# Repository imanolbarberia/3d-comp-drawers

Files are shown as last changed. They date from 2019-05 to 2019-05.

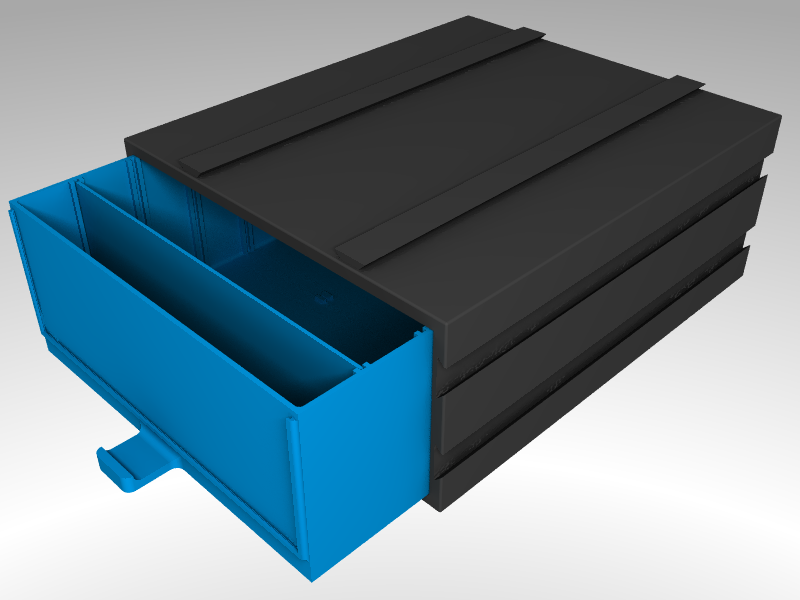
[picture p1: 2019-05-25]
renderer/1story_big.png

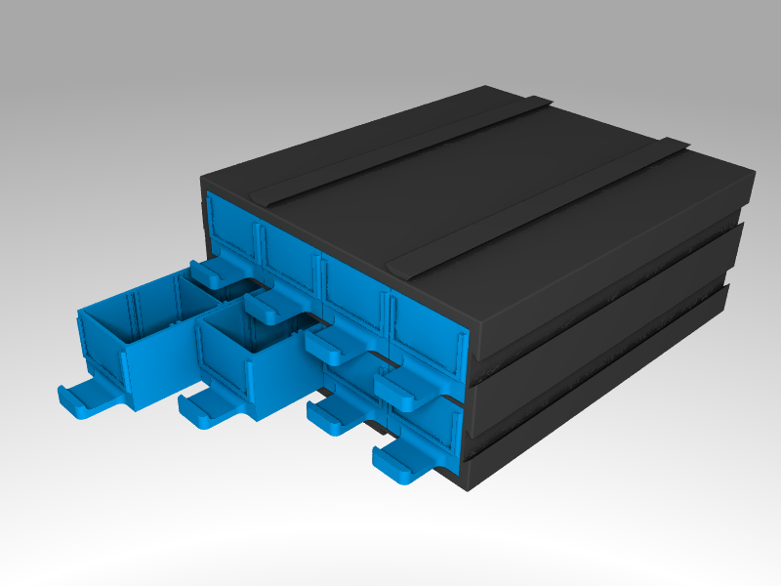
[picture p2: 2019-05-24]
renderer/2story_small.png

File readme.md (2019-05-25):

# Electronic Components Drawers and Cabinet

This project is for creating a cabinet and drawers for storing electronic components and small parts. Preferably only free and open source tools will be used, but in some cases it may not be feasible.

---
### Status
* Version: v2.0
* Released 
  * 1 story version: https://www.thingiverse.com/thing:3651857
  * 2 story version: https://www.thingiverse.com/thing:2868765
---
### Tools used
##### Software:
* [FreeCAD](https://www.freecadweb.org/): 3D CAD software
* [Ultimaker Cura](https://ultimaker.com/en/products/ultimaker-cura-software): Slicing software for converting 3D models into printable objects
##### Hardware:
* [Anycubic I3 Mega](https://www.amazon.com/Anycubic-3D-171-Upgraded-PRINTER-Heated/dp/B074NZPHJ5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): 3D printer

---
### Authors:
* Imanol Barberia (imanol.barberia@gmail.com)

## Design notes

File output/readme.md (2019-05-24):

### /output/
This is the output folder, where all the printable files will be stored

### STL Files
* **cabinet.stl**: Mesh for the cabinet object
* **drawer_tiny.stl**: Mesh for the Tiny drawer object
* **drawer_small.stl**: Mesh for the Small drawer object
* **drawer_standard.stl**: Mesh for the Standard drawer object
* **drawer_big.stl**: Mesh for the Big drawer object

### GCode
3D printing parameters used for the models:
* **Layer height**: 0.2 mm
* **Printing temperature**: 210 ºC
* **Build plate temperature**: 50 ºC
* **Enable retraction**: Yes
* **Print speed**: 60 mm/s
* **Travel speed**: 120 mm/s
* **Generate support**: No

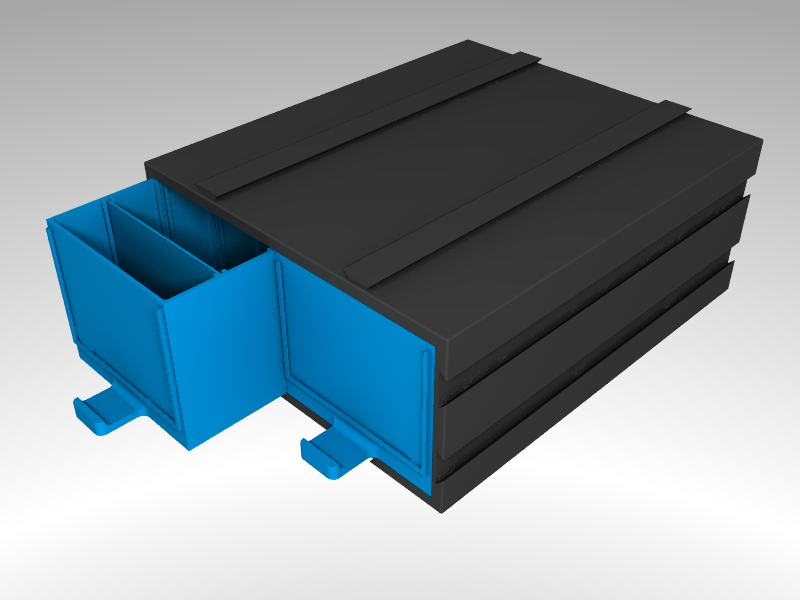
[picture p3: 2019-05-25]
renderer/1story_standard.png

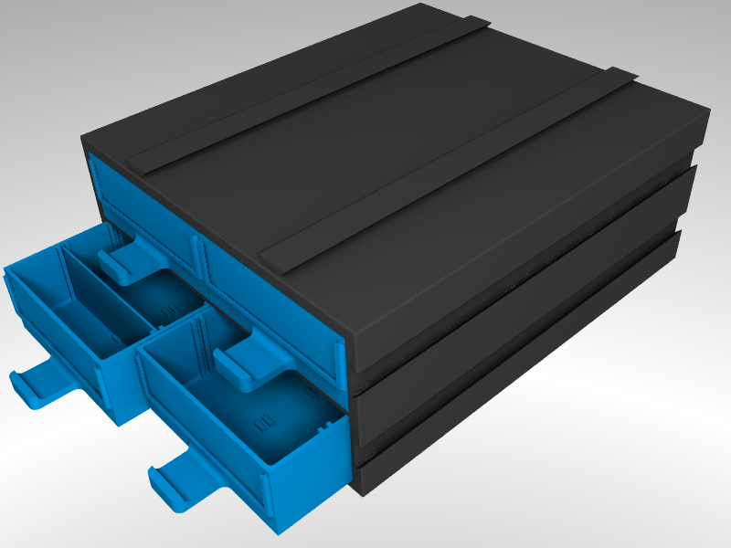
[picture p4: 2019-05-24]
renderer/2story_standard.png

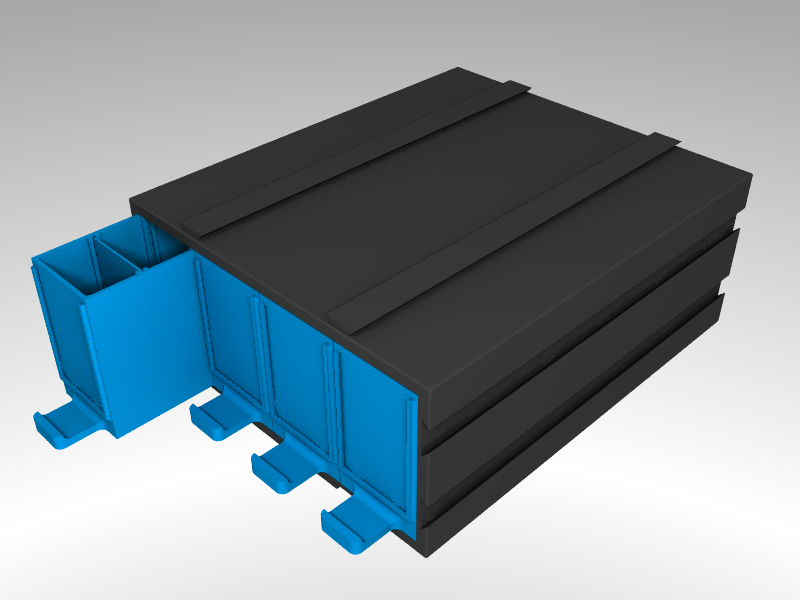
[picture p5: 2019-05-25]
renderer/1story_small.png

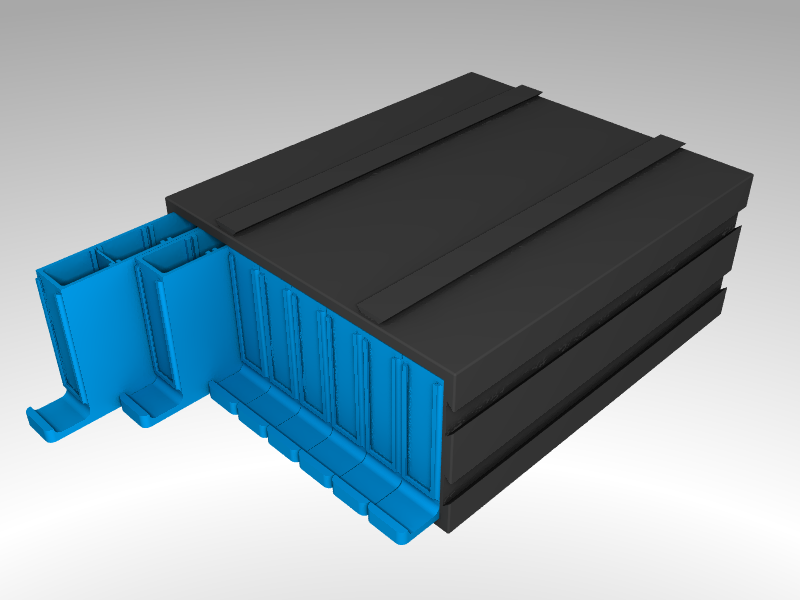
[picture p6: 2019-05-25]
renderer/1story_tiny.png

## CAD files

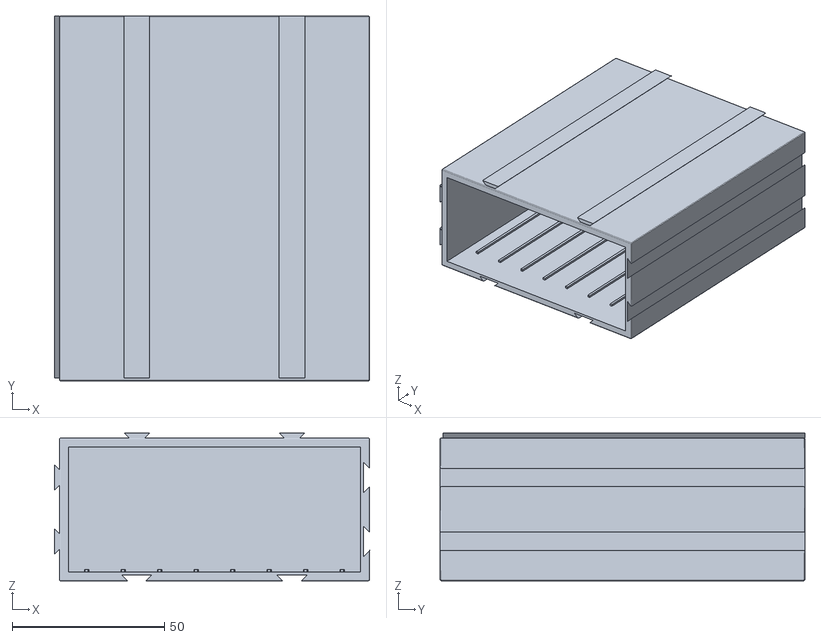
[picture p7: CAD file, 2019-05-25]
output/1story_cabinet.stl
103.6 x 120.0 x 48.6

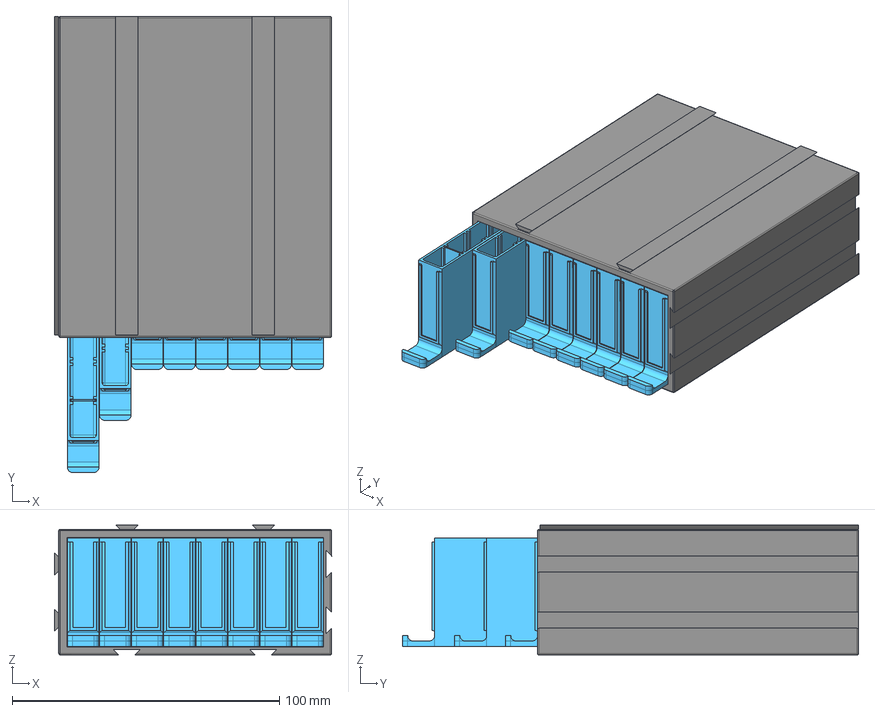
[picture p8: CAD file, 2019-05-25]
renderer/1story_renderer.fcstd
103.6 x 170.5 x 48.6 mm
tiny_separator_000
tiny_drawer_000
tiny_drawer_001
tiny_drawer_002
tiny_drawer_003
tiny_drawer_004
tiny_drawer_005
tiny_drawer_006
tiny_drawer_007
FinalCabinet

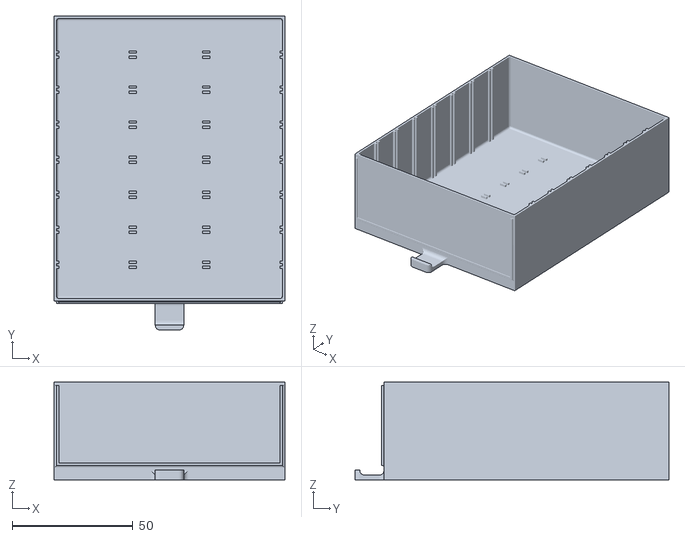
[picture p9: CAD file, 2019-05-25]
output/1story_drawer_big.stl
95.5 x 130.0 x 40.5

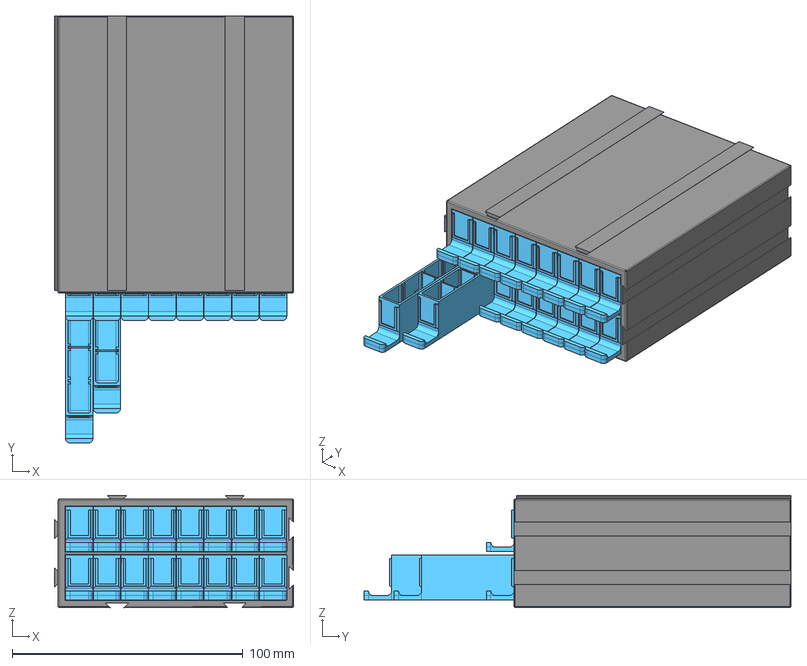
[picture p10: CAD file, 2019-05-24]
renderer/2story_renderer.fcstd
103.6 x 185.0 x 48.6 mm
tiny_separator_000
tiny_separator_001
tiny_separator_002
tiny_separator_003
tiny_drawer_000
tiny_drawer_001
tiny_drawer_002
tiny_drawer_003
tiny_drawer_004
tiny_drawer_005
tiny_drawer_006
tiny_drawer_007
tiny_drawer_014
tiny_drawer_008
tiny_drawer_011
tiny_drawer_013
tiny_drawer_010
tiny_drawer_015
tiny_drawer_009
tiny_drawer_012
Final Cabinet

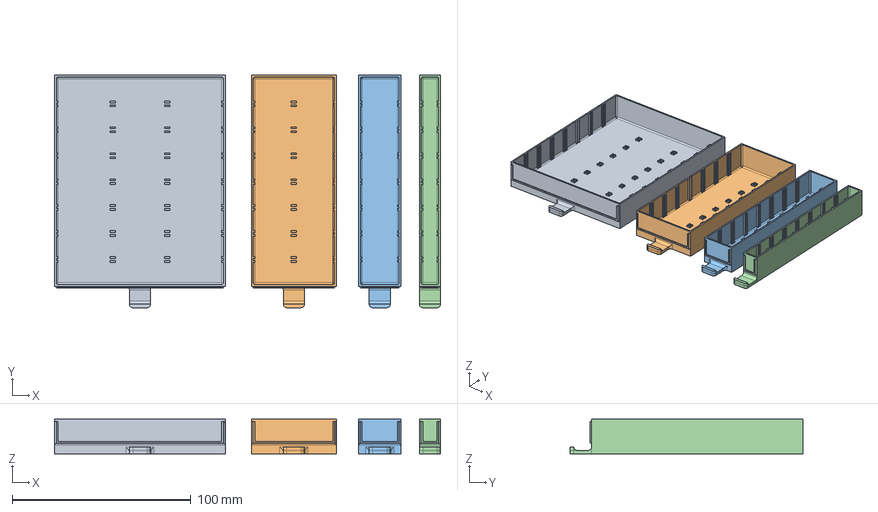
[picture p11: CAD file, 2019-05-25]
src/2story_drawers.fcstd
215.8 x 130.0 x 19.5 mm
BigDrawer
StandardDrawer
SmallDrawer
TinyDrawer

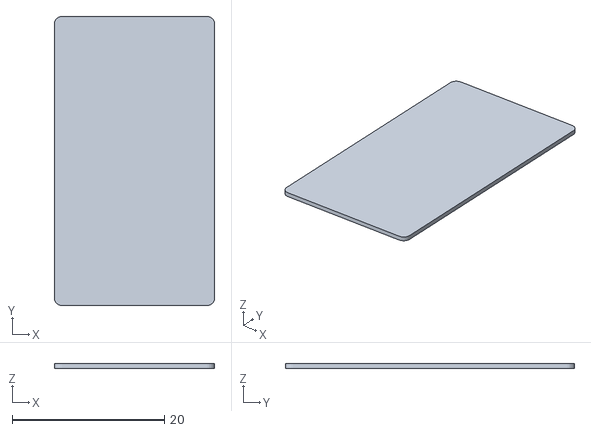
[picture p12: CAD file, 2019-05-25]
output/1story_separator_small.stl
21.1 x 38.0 x 0.6

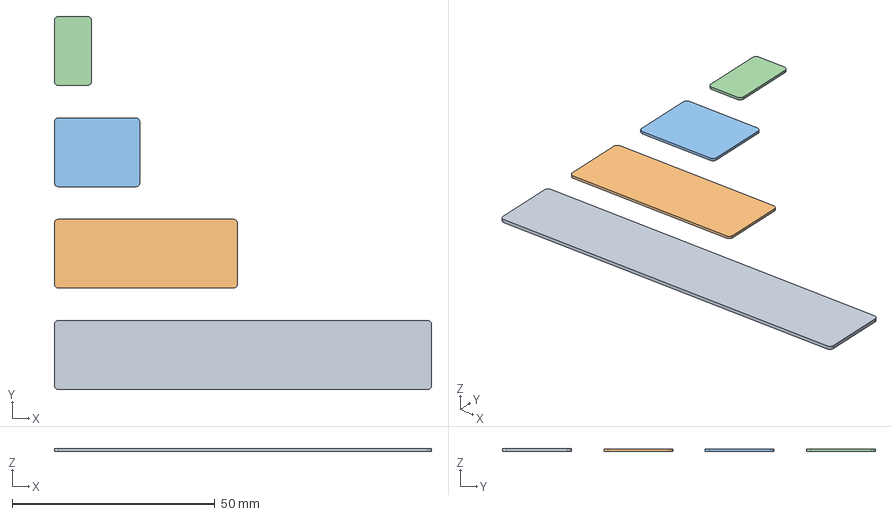
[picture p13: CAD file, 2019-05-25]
src/2story_separators.fcstd
93.1 x 92.0 x 0.8 mm
BigSeparator
StandardSeparator
SmallSeparator
TinySeparator

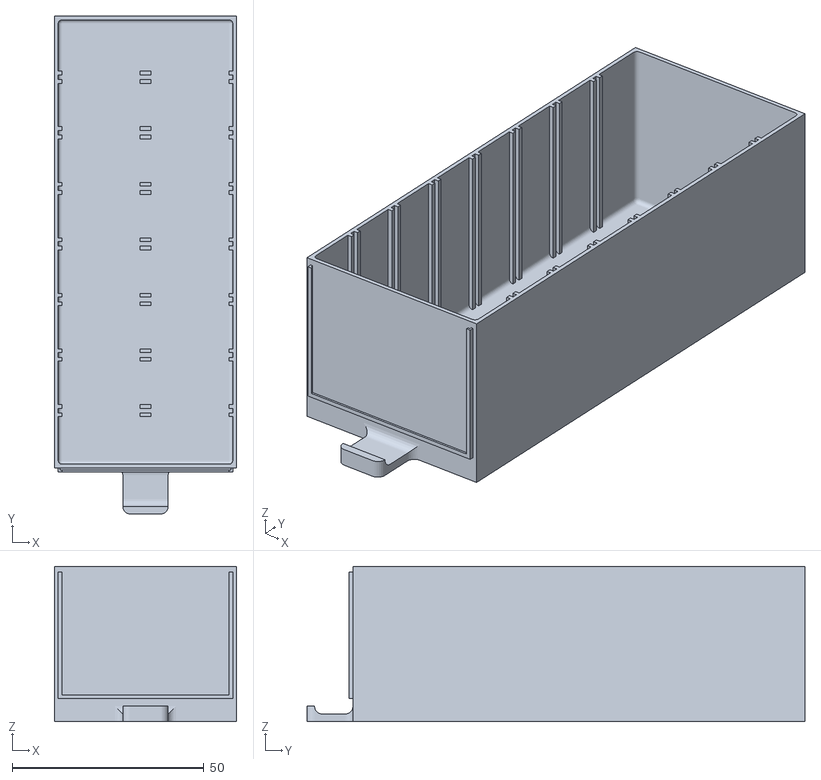
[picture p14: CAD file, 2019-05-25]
output/1story_drawer_standard.stl
47.6 x 130.0 x 40.5

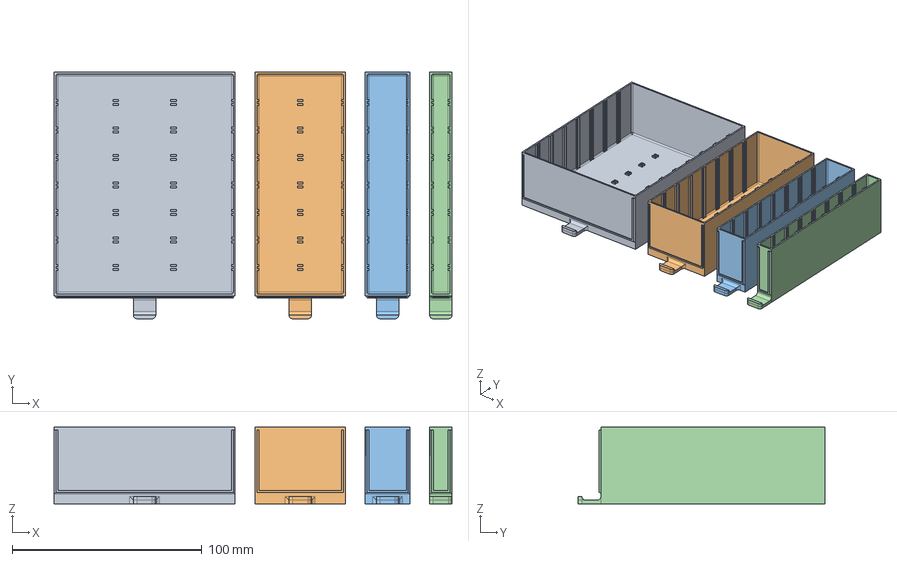
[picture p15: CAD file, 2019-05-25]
src/1story_drawers.fcstd
209.8 x 130.0 x 40.5 mm
BigDrawer
StandardDrawer
SmallDrawer
TinyDrawer

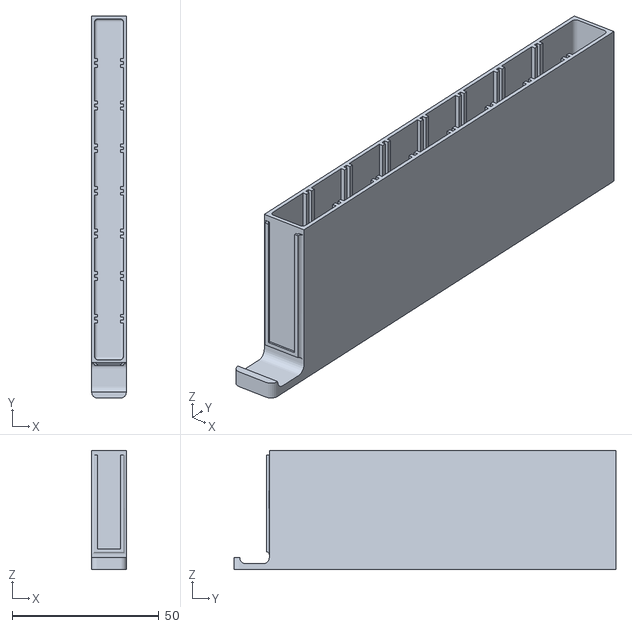
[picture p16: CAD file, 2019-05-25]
output/1story_drawer_tiny.stl
11.8 x 130.0 x 40.5

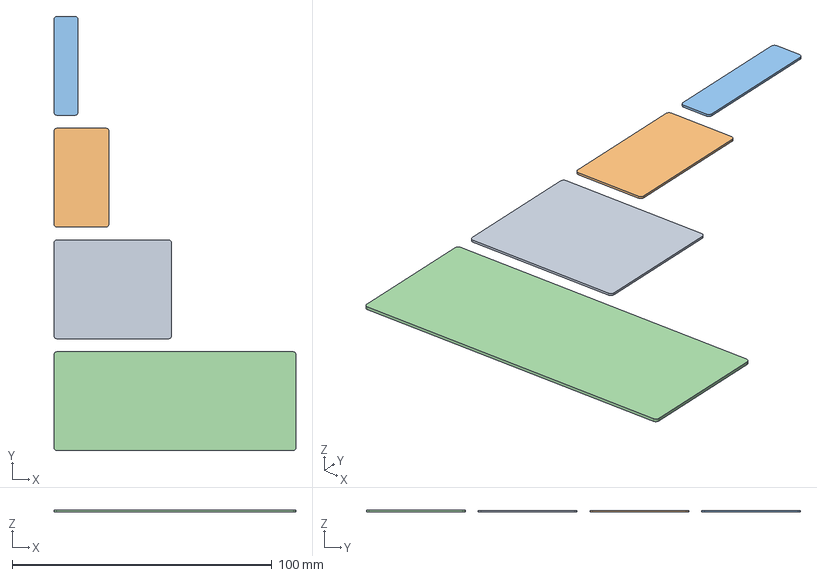
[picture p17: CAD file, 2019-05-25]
src/1story_separators.fcstd
93.1 x 167.0 x 0.8 mm
StandardSeparator
SmallSeparator
TinySeparator
BigSeparator

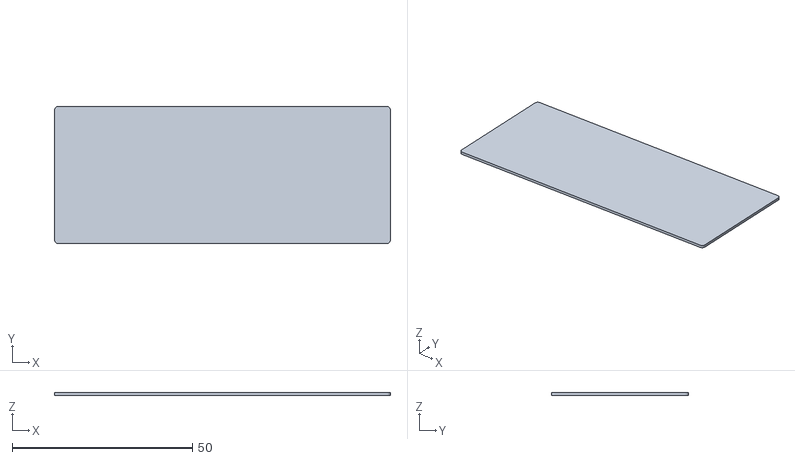
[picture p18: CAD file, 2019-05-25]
output/1story_separator_big.stl
93.1 x 38.0 x 0.8

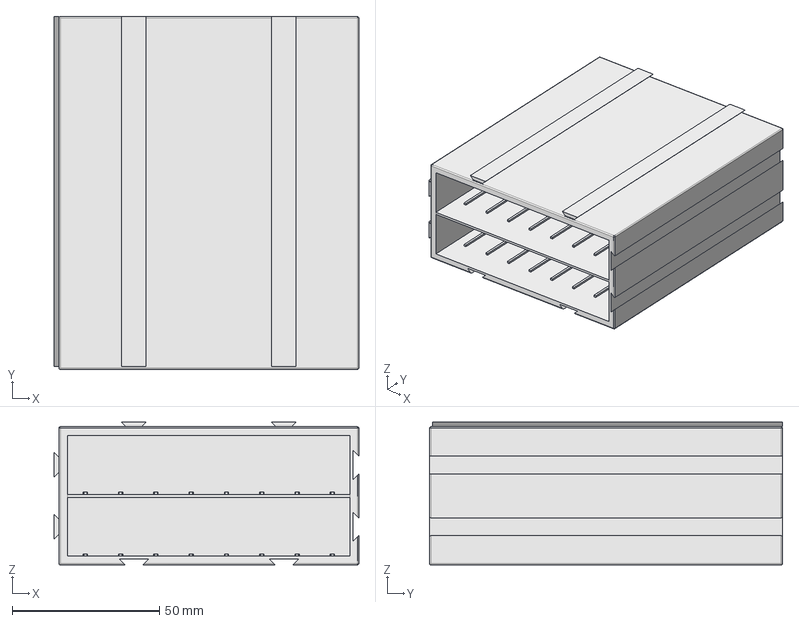
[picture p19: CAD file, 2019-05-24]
src/2story_cabinet.fcstd
103.6 x 120.0 x 48.6 mm

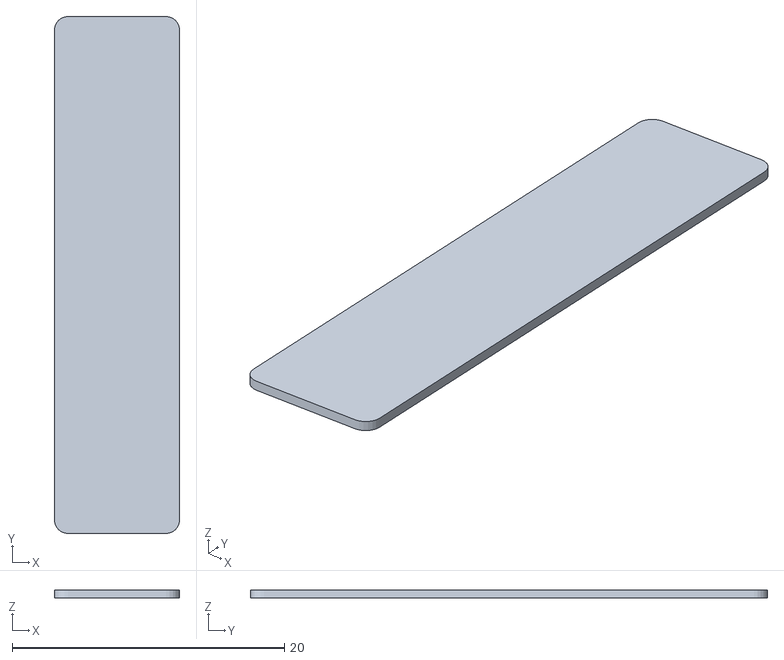
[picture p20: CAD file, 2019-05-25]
output/1story_separator_tiny.stl
9.20 x 38.0 x 0.6

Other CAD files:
src/1story_cabinet.fcstd
output/1story_drawer_small.stl
output/1story_separator_standard.stl
output/2story_drawer_standard.stl
output/2story_cabinet.stl
output/2story_drawer_big.stl
output/2story_drawer_small.stl
output/2story_drawer_tiny.stl
output/2story_separator_big.stl
output/2story_separator_small.stl
output/2story_separator_standard.stl
output/2story_separator_tiny.stl

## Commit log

2018-04-16 [PROJ-11] Designed v1.0 for cabinet
    [cabinet.fcstd, cabinet.stl]
2018-04-16 [PROJ-11] Added Tiny drawer design
    [drawer_tiny.fcstd, drawer_tiny.stl]
2018-04-16 [PROJ-11] Fixed Tiny Drawer name in FreeCAD
    [drawer_tiny.fcstd]
2018-04-16 [PROJ-11] Added Small drawer design
    [drawer_small.fcstd, drawer_small.stl]
2018-04-16 [PROJ-11] Added Standard drawer design
    [drawer_standard.fcstd, drawer_standard.stl]
2018-04-16 [PROJ-11] Added Big drawer design
    [drawer_big.fcstd, drawer_big.stl]
2018-04-16 [PROJ-15] Added supports for stackability
    [cabinet.fcstd, cabinet.stl]
2018-04-17 [PROJ-18] Enlarged Tiny drawer's handler
    [drawer_tiny.fcstd, drawer_tiny.stl]
2018-04-17 [PROJ-18] Enlarged Small drawer's handler
    [drawer_small.fcstd, drawer_small.stl]
2018-04-17 [PROJ-18] Enlarged Standard drawer's handler
    [drawer_standard.fcstd, drawer_standard.stl]
2018-04-17 [PROJ-18] Enlarged Big drawer's handler
    [drawer_big.fcstd, drawer_big.stl]
2018-04-17 [PROJ-16] Filled the support holes (bottom) to be non go-through
    [cabinet.fcstd, cabinet.stl]
2018-04-17 Added renderer project for rendering final simulations
    [renderer.fcstd]
2018-04-18 [PROJ-20] Fixed drawer tolerances
    [drawer_small.fcstd, drawer_small.stl, drawer_standard.fcstd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]
2018-04-18 [PROJ-19] Added guides in drawers
    [drawer_big.fcstd, drawer_big.stl, drawer_small.fcstd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]
2018-04-18 [PROJ-19] Added guides for cabinet
    [cabinet.fcstd, cabinet.stl]
2018-04-19 Updated renderer data
    [renderer.fcstd]
2018-04-19 [PROJ-22] Modified guides in the cabinet to match a correct size
    [cabinet.fcstd, cabinet.stl]
2018-04-19 [PROJ-23] Added guides test model
    [guides_test.fcstd, guides_test.stl]
2018-04-19 [PROJ-25] Reduced top buttons size by 0,25 mm radius
    [cabinet.fcstd, cabinet.stl]
2018-04-20 [PROJ-26] Added separator for tiny drawers
    [drawer_tiny.fcstd, drawer_tiny.stl, separator_tiny.fcstd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]
2018-04-20 [PROJ-26] Added separator for small drawers
    [drawer_small.fcstd, drawer_small.stl, separator_small.fcstd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]
2018-04-20 [PROJ-26] Added separator for standard drawers
    [drawer_standard.fcstd, drawer_standard.stl, separator_standard.fcstd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]
2018-04-20 [PROJ-26] Added separator for big drawers
    [drawer_big.fcstd, drawer_big.stl, separator_big.fcstd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]
2018-04-21 [PROJ-22] Fixed (again) the guides' size, from 1.8 to 1.5 mm on the widest part
    [cabinet.fcstd, cabinet.stl]
2018-04-21 [PROJ-XXX] Fixed standard separator dimensions
    [separator_standard.fcstd, separator_standard.stl]
2018-04-21 [PROJ-27] Added renders for every kind of drawer
    [renderer.fcstd]
2018-04-22 [PROJ-28] Redesigned tiny drawer
    [drawer_tiny.fcstd, drawer_tiny.stl, separator_tiny.fcstd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]
2018-04-25 [PROJ-28] Redesigned tiny drawer handler, guide and separators
    [drawer_tiny.fcstd, drawer_tiny.stl, separator_tiny.fcstd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]
2018-04-25 [PROJ-28] Redesigned small drawer separator
    [drawer_small.fcstd, drawer_small.stl, separator_small.fcstd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]
2018-04-25 [PROJ-28] Redesigned Standard Drawer separator
    [drawer_standard.fcstd, drawer_standard.stl, separator_standard.fcstd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]
2018-04-25 [PROJ-28] Redesigned Big Drawer separator
    [drawer_big.fcstd, drawer_big.stl, separator_big.fcstd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]
2018-04-25 [PROJ-30] Modified guides in the cabinet
    [cabinet.fcstd, cabinet.stl]
2018-04-25 [PROJ-30] Redesigned small drawer guide
    [drawer_small.fcstd, drawer_small.stl]
2018-04-25 [PROJ-30] Redesigned standard drawer guide
    [drawer_standard.fcstd, drawer_standard.stl]
2018-04-25 [PROJ-30] Redesigned big drawer guide
    [drawer_big.fcstd, drawer_big.stl]
2018-04-25 [PROJ-29] Redesigned tiny drawer handler
    [drawer_tiny.fcstd, drawer_tiny.stl]
2018-04-25 [PROJ-29] Redesigned small drawer handler
    [drawer_small.fcstd, drawer_small.stl]
2018-04-25 [PROJ-29] Redesigned standard drawer handler
    [drawer_standard.fcstd, drawer_standard.stl]
2018-04-25 [PROJ-29] Redesigned big drawer handler
    [drawer_big.fcstd, drawer_big.stl]
2018-04-25 Updated renderer for v1.5
    [renderer.fcstd]
2018-04-25 [PROJ-31] Modified big separator size
    [separator_big.fcstd, separator_big.stl]
2018-04-25 [PROJ-31] Modified standard separator size
    [separator_standard.fcstd, separator_standard.stl]
2018-04-25 [PROJ-31] Modified small separator size
    [separator_small.fcstd, separator_small.stl]
2018-04-26 [PROJ-32] Redesigned separator holder for Big drawer
    [drawer_big.fcstd, drawer_big.stl]
2018-04-26 [PROJ-33] Redesigned separator holder for Standard drawer
    [drawer_standard.fcstd, drawer_standard.stl]
2018-04-28 [PROJ-32] Added double bottom separator holder for Big Drawer
    [drawer_big.fcstd, drawer_big.stl]
2018-04-30 [PROJ-32] Adjusted Big drawer separator to fit correctly
    [separator_big.fcstd, separator_big.stl]
2018-05-02 [PROJ-33] Fixed Standard drawer separator size
    [separator_standard.fcstd, separator_standard.stl]
2018-05-02 [PROJ-36] Added label holder for Tiny drawer
    [drawer_tiny.fcstd, drawer_tiny.stl]
2018-05-02 [PROJ-37] Added label holder for Small drawer
    [drawer_small.fcstd, drawer_small.stl]
2018-05-02 [PROJ-37] Added fillet to the label holder
    [drawer_small.fcstd, drawer_small.stl]
2018-05-02 [PROJ-38] Added label holder for Standard drawer
    [drawer_standard.fcstd, drawer_standard.stl]
2018-05-02 [PROJ-39] Added label holder for Big drawer
    [drawer_big.fcstd, drawer_big.stl]
2018-05-02 [PROJ-40] Added side guides for side stacking
    [cabinet.fcstd, cabinet.stl]
2018-05-04 [PROJ-40] Fixed guide sizes
    [cabinet.fcstd, cabinet.stl]
2018-05-04 [PROJ-42] Redesigned Tiny drawer handler and label holder
    [drawer_tiny.fcstd, drawer_tiny.stl]
2018-05-04 [PROJ-43] Redesigned Small drawer handler and label holder
    [drawer_small.fcstd, drawer_small.stl]
2018-05-05 [PROJ-45] Redesigned Big drawer handler and label holder
    [drawer_big.fcstd, drawer_big.stl]
2018-05-05 [PROJ-44] Redesigned Standard drawer handler and label holder
    [drawer_standard.fcstd, drawer_standard.stl]
2018-05-05 Updated renderer scenes for v1.7
    [renderer.fcstd]
2018-06-30 Added labels template
    [labels_template.ods]
2018-06-30 Updated labesl with capacitors
    [labels_template.ods]
2019-05-24 [close #2] Add top and bottom external guides
    [cabinet.fcstd]
2019-05-24 Fix missing fillet in the outer edges
    [cabinet.fcstd]
2019-05-24 [close #1] Remove inner gap on drawer handlers
    [drawer_big.fcstd, drawer_small.fcstd, drawer_standard.fcstd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]
2019-05-24 Update STL files
    [cabinet.stl, drawer_big.stl, drawer_small.stl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]
2019-05-24 Update render views for new cabinet and drawers
    [renderer.fcstd]
2019-05-24 [close #6] unify files
    [cabinets.fcstd, drawer_big.fcstd, drawer_small.fcstd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]
2019-05-24 update file structure to hold new 1story files
    [2story_cabinet.fcstd, 2story_cabinet.stl, 2story_drawer_big.stl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]
2019-05-24 [close #3] add 1 story cabinet
    [1story_cabinet.fcstd]
2019-05-25 [close #4] create 1 story drawers
    [1story_drawers.fcstd]
2019-05-25 [close #5] create 1 story separators
    [1story_separators.fcstd]
2019-05-25 [close #8] create STL files for 1 story objects
    [1story_cabinet.stl, 1story_drawer_big.stl, 1story_drawer_small.stl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]
2019-05-25 [close #7] create renders for 1 story objects
    [1story_renderer.fcstd]
2019-05-25 add labels template for 1 story
    [1story_labels_template.ods]
